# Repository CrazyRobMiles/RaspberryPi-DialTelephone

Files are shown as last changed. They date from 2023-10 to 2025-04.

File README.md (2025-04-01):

# Raspberry Pi 
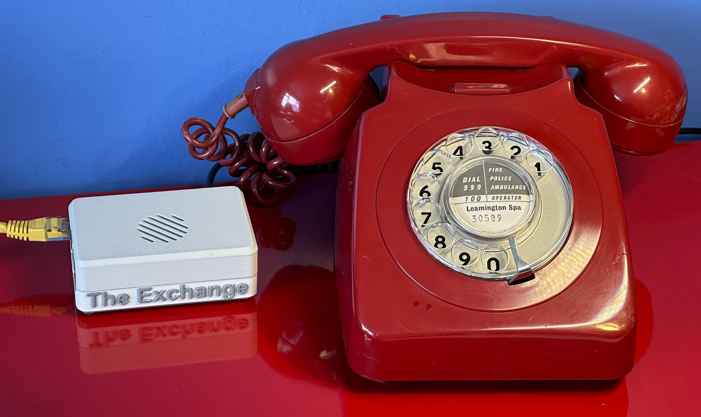
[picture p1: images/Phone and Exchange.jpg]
Red Phone


Make an old-style dial telephone into something a bit more interesting. Now with added Exchange.

## Videos

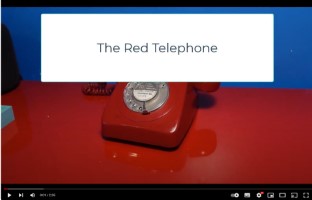
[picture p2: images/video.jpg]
YouTube Screenshot (https://youtu.be/aNzIdzsJkjI)


To find out more about the phone click on the image above to see a short video.

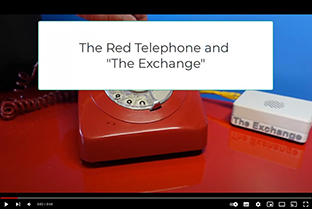
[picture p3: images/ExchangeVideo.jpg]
YouTube Screenshot (https://youtu.be/p6Ti9BQiqs0)


To see The Exchange in action click on the image above to see an  even shorter video.

## Building the device
The parts you'll need are as follows:

* An old-style telephone with a dial. The author used a 746 model he picked up in a second-hand shop. 

* I think the phone should be red, like the original “batphone” but the software will work with other colours.
* A Raspberry Pi Zero 2. Any colour you like.
* Two power switches for the bell. The author used a design which had dual D4184 MOSFETs. This can be driven directly by the GPIO signals from the Raspberry Pi.
* Two 1N4007 1A 1000V Silicon Rectifier Diodes. These are wired across the outputs from the D4184 switches so that when the bell coils are switched off the voltage induced by collapse of the magnetic in coil doesn't destroy the switch. You can see them on the circuit diagram below. Make sure you wire them the correct way round, with the band towards the positive line. 
* A power supply to convert 12 volts to 35 volts for the bell.
* A power supply to convert 12 volts to 5 volts for the Raspberry Pi.
* A 12-volt power supply for the above. 
* A Raspberry Pi GPIO breakout board to mount all the components. 
* A USB audio adapter and micro-USB “on the go” cable to connect it.

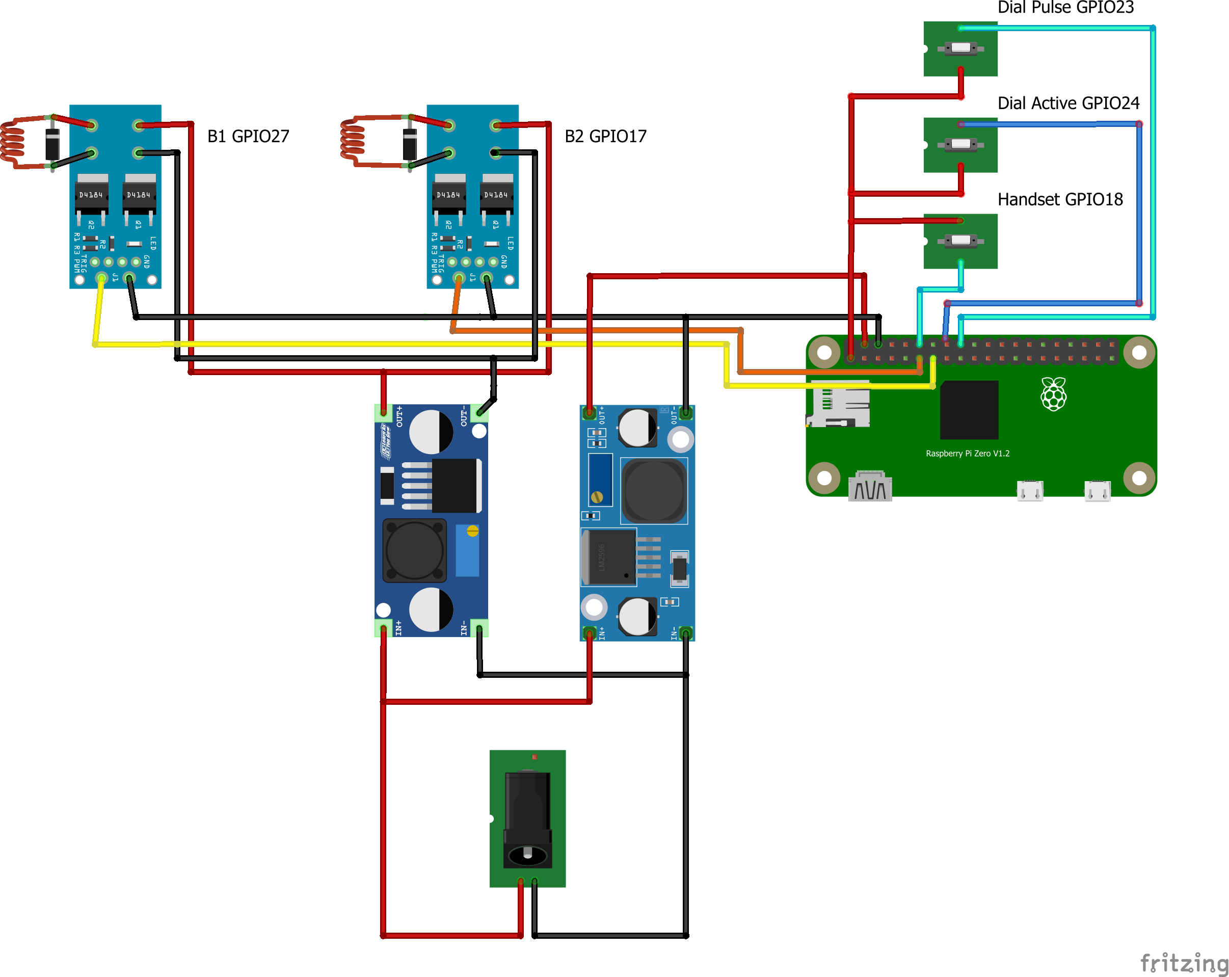
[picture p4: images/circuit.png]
Circuit diagram


The Raspberry Pi GPIO pins are shown on the circuit diagram. There is also a USB sound interface plugged into the Raspberry Pi "On the Go" usb socket via a suitable adapter. 
## Packaging the components
pi holder
There is a 3D printable design for the Raspberry Pi holder in the holder folder.
built system
This is the built system.
## Setting up the Raspberry Pi
Steps to install software:
### Make an sd card for your Pi
1. Start the Raspberry Imager program on your machine and put the microSD card into the drive on your computer. 
1. Select the OS to be installed. Make sure you are not installing a desktop. You will be using your Raspberry Pi without a screen, keyboard or mouse. (I used Debian Bullseye Light)
1. Set the advanced options in the Imager program. Now make the folling settings. 
    1. Hostname (I called mine "theredphone")
    1. Enable SSH (password authentication)
    1. User: xxxx Password: xxxxxx (don't use x, put in your own words) I created a user called rob (it's used in the ssh command a few steps down)
    1. Set Wi-Fi credentials and locale
    1. Save the options so you can use them again if you need to
1. Make the image.
### Configure your Pi
1. Remove the SD card from your computer, plug it into your Raspberry Pi and turn the Pi on. Wait a few minutes until the green led on the Pi seems to settle down a bit.
1.	Now log in from your computer. You'll need a command prompt to do this. The commands given are from Microsoft PowerShell. You will be setting up a secure shell, so use the command ssh:
    ```
    ssh theredphone.local -l rob
    ```
1.	Use the name of the computer and the username that you set in the steps above. Say yes to set up the connection if it is the first time you've connected.
1.	Give your password when it is requested.
1.  Once you've logged in you should update your computer:
    ```
    sudo apt update
    ```
1.	Now set up SSL to allow your remote machine to connect to the PI.
    1. On the Pi
        1. Check for existing SSH
            ```
            ls ~/.ssh
            ```
        1. If this comes back with some files they are already there. Otherwise:
            ```
            ssh-keygen
            ```

        1.	Use the defaults
    1.	On your remote machine
        1.	Copy your keys over:
            ```
            cat ~/.ssh/id_rsa.pub | ssh rob@theredphone.local 'mkdir -p ~/.ssh && cat >> ~/.ssh/authorized_keys'
            ```

        1. I used the username and the address of the pi I’m setting up. Enter the password for the user (in my case rob)
    1. Now you can test the connection. Open another terminal window on your remote machine and connect directly to the pi with no password:
        ```
        ssh theredphone.local -l rob
        ```
    1. This should open a remote terminal session with no password required. If this works you will be able to use remote development with Visual Studio Code.
### Install git
1. Now we need to install git on your machine:
    ```
    sudo apt-get install git -y
    ```
1. Next we need to configure the username and email values for the Git installation on the machine. Use your email and username as appropriate. 
    ```
    git config --global user.name "Rob Miles"
    git config --global user.email rob@robmiles.com
    ```
### Install node 

1.	Now install nodejs and npm:
    ```
    sudo apt install nodejs
    sudo apt install npm
    ```
### Install audio output and speech
1.  Install the audio headers for the espeak:
    ```
    sudo apt-get install libasound2-dev
    ```
1.	Now install espeak:
    ```
    sudo apt-get install espeak
    ```
1.	Now set up the audio playback. This is going to make the USB sound adapter the default audio device. If you try to run the server without the audio interface plugged in the phone software will fail:
    ```
    sudo nano /usr/share/alsa/alsa.conf
    ```
    1.  Find:
        ```
        defaults.ctl.card 0
        defaults.pcm.card 0
        ```
    1.	Change to: 
        ```
        defaults.ctl.card 1
        defaults.pcm.card 1
        ```
    1. reboot the machine
        ```
        sudo reboot
        ```
### Start developing with Visual Studio Code
Will be developing the code on our PC or laptop. The version of Visual Studio Code on that device will communicate with remote connection software running on the Raspberry Pi. 
1.	Open Visual Studio Code on your PC or laptop. 
1.	Make sure to turn off things that slow us down. 
    1. Select the Extensions tab and enter the following into the extensions search window:
        ```
        @builtin typescript
        ```
    1. Two plugins should be found. Click the gear icon and select "Disable Workspace" from the menu for each. You will lose a few useful features when editing the code, but at least the Raspberry Pi won't freeze up.
1. Ensure you have Remote Development installed on your machine. If you don't, open extensions and install it. If it is installed you will have a green icon in the bottom left of your Visual Studio Window. Click this to open a remote development window.
1.  Select "Connect to Host - Remote SSH" from the menu which appears. The first time you make the connection you will be asked to enter the username and address of your machine. I used rob@redphone.local - you use the one you set. 
1. Create a new remote connection (rob@theredphone.local)
1.	Now clone the repository.
    1. Select "Clone a repository" from the start page of Visual Studio Code and open the following repository:
    ```
    https://github.com/CrazyRobMiles/RaspberryPi-DialTelephone
    ```
1. Now we need to install all the libraries in the project (we only need to do this once)
    ```
    npm install
    ```
1. Now open a terminal window and start the server:
    ```
    node redserver.js
    ```
The server should start up and you can interact with the phone. 
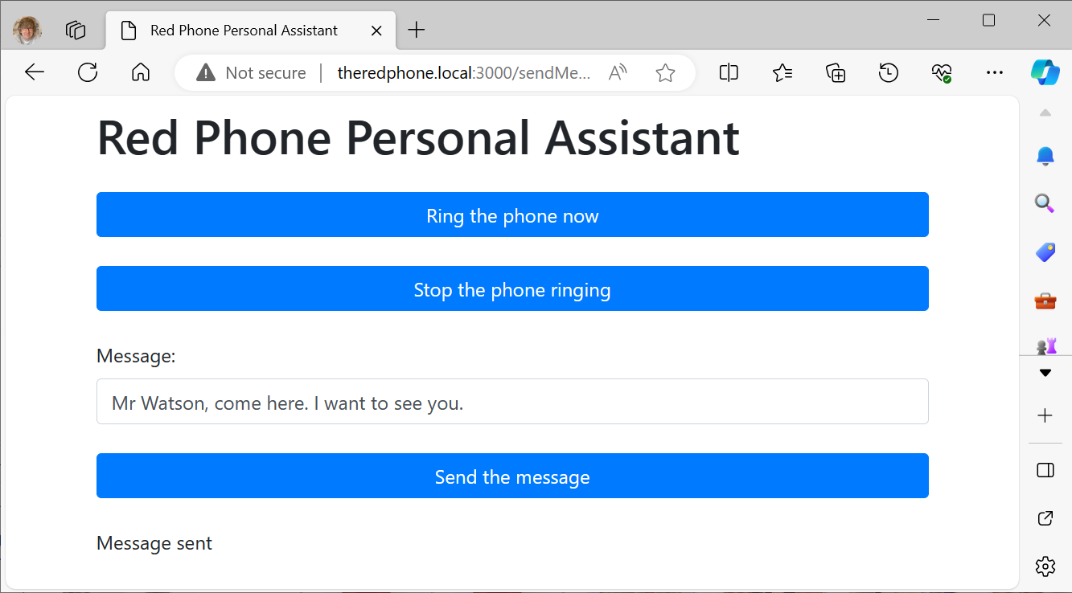
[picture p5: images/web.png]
Web Interface

If you want to make the server run automatically when the Raspberry Pi starts you can do this by editing the rc.local file. 
# Adding sound input
You can make your phone even more interesting by adding audio input. You can use this to record messages or, by using speech to text, understand voice commands. 
## Sound input circuit

You can add voice input to the phone by building a small circuit and connecting it to the carbon microphone in the telephone handset. The sound quality is not as good as a modern microphone, but it does work with speech recognition and it has the "authentic telephone" sound.

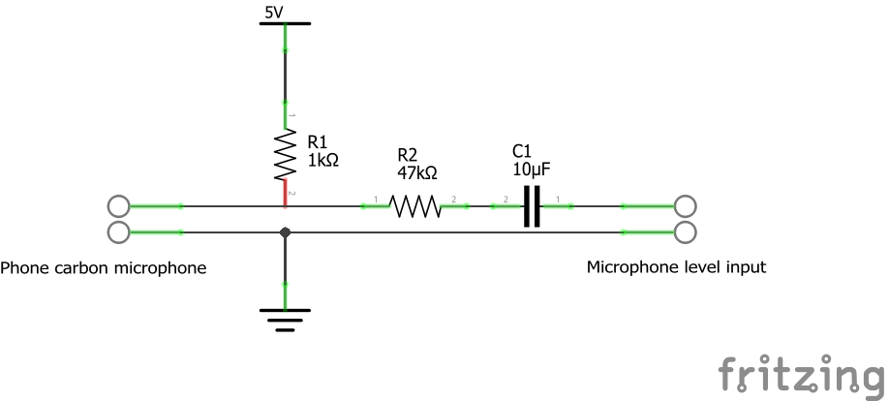
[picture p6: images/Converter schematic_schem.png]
microphone converter circuit


The circuit above alows the phone handset microphone to be connected to a standard microphone input such as the one fitted to USB audio converter you might use with a Raspberry Pi. 
## Recording audio
The application uses the mic application to record audio. It is called from within the helper function /helpers/soundInput.js.

## Speech to text software
The updated phone software uses the Spchcat program you can find [here](https://github.com/petewarden/spchcat) The program runs on a Raspberry Pi Zero but it takes a few seconds to complete a conversion. 

Follow the instructions on the repository to install the software. It is called from within the phone software by the helper function in /helpers/speechInput.js. 

# The Exchange
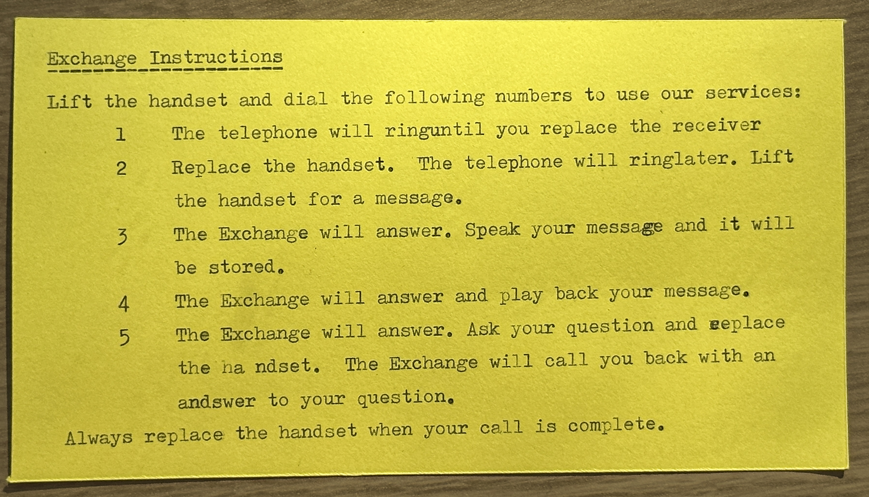
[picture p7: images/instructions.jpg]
the instructions for the telephone

"The Exchange" is a Raspberry Pi running a Large Language Mode (LLM). You will need a Raspberry Pi 5 with 8Gb of memory and an SSD. The telephone can connect to this and send it questions which will be answered by a returned telephone call. Note that in the code the exchange has the network address http://ssdpi.local. YOu can change this by editing the LLM.js code in the helpers folder.

## Installing the LLM
You can install the LLM on your Pi by following the instructions [here](https://medium.com/@wesselbraakman/run-llama-on-your-raspberry-pi-5-without-using-ollama-7ebc128ff34e). This requires the use of a Linux PC (or a Windows PC running the Windows Subsystem for Linux).
## Building and running the LLM web server
Once you have installed the LLM on your Exchange Pi and tested it with the chat program you need to build and start the web service that the Raspberry Pi phone will talk to. This is the procedure for building the server.

1.  Use Visual Studio Code to open the llma-cpp project that you installed on your Pi. 

1. Install the CMake plugin for VS Code (I installed the Microsoft one)

1. Set the development environment in Visual Studio Code (there is only one option on the PI).

1.  Install cmake on the pi.

1.  Use make from the terminal in Visual Studio Code to build the code

1.  Start the server with the command below in the Visual Studio Terminal. Note the path to the llm and also the host.
    ```
    ./server -m models/llama-7b/ggml-model-q4_0.gguf -c 2048 --host 0.0.0.0
    ```
1.  You can now browse to the page (my pi is called ssdpi)
    ```
    http://ssdpi.local:8080/ 
    ```

Have fun

Rob Miles

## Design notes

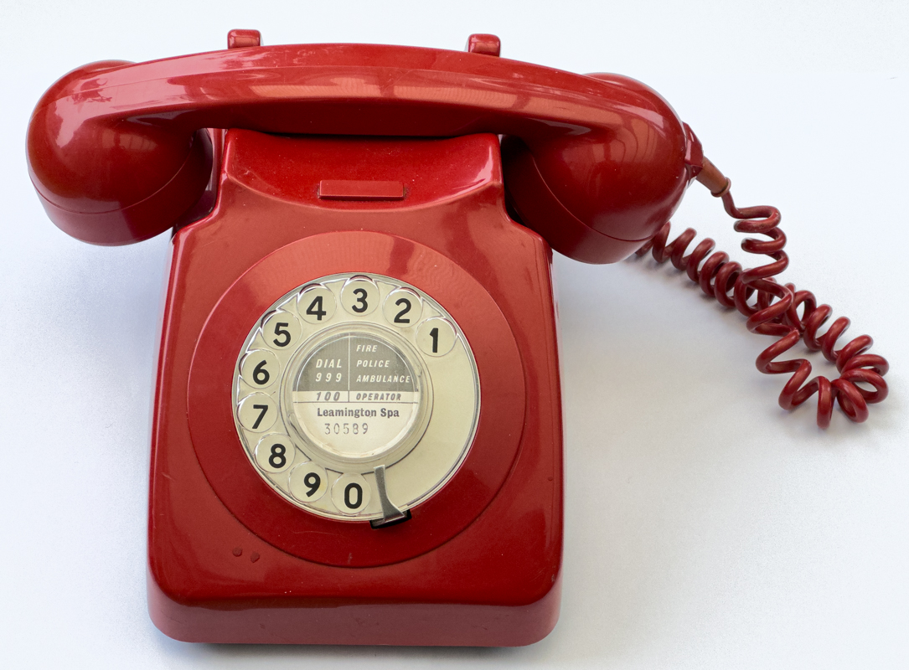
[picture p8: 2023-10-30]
images/RedPhone.jpg

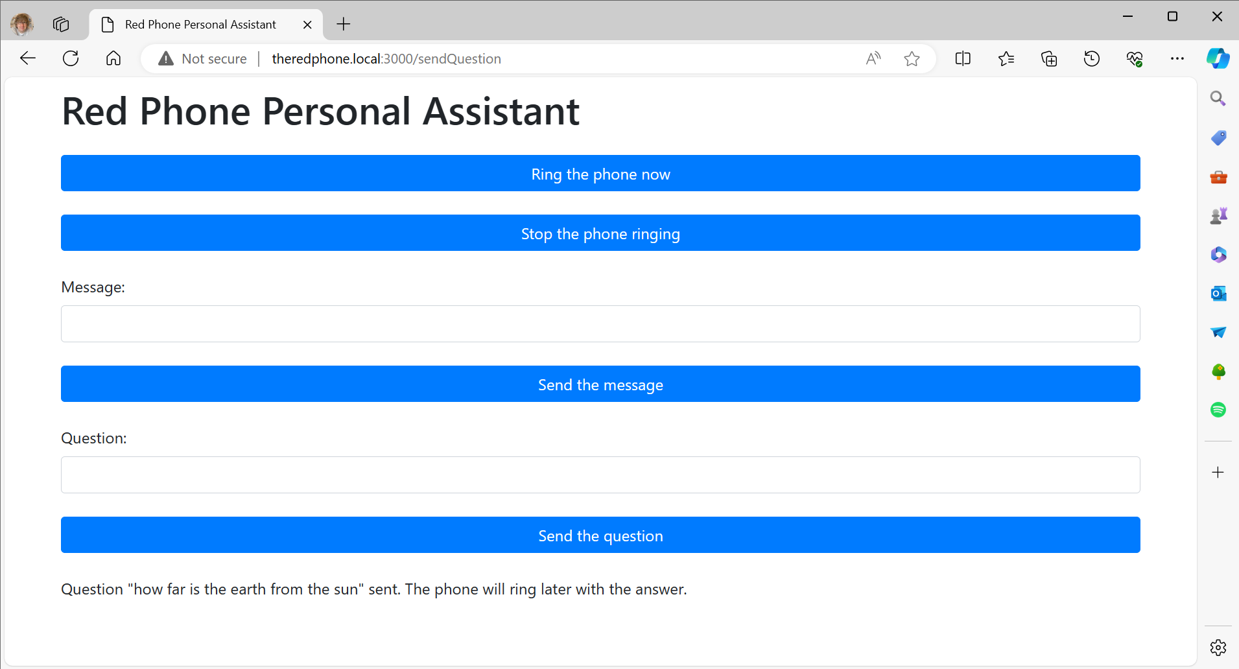
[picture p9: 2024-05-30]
images/Phone and Exchange.png

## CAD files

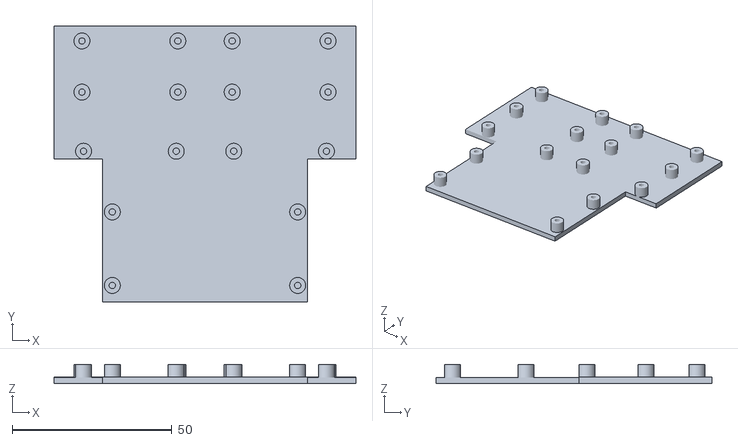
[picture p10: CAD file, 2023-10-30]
holder/PiHolder.stl
94.5 x 86.5 x 6.00

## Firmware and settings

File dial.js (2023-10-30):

const InGPIO = require('./helpers/InGPIO');

class Dial{

    dialing = false;

    pulseHandler(value){
        console.log(`Pulse handler:${value}`);
        console.log(Dial.dialing);
    }

    dialHandler(value){
        console.log(`Dial handler:${value}`);
    }

    startDialing(){
        this.dialing = true;
        this.pulseCount = 0;
        this.owner.dialStarted();
    }

    dialPulse(){
        if(this.dialing){
            this.pulseCount++;
            this.owner.dialPulse();
        }
    }

    endDialing(){
        console.log(`    Dialed a:${this.pulseCount}`);
        this.owner.numberDialed(this.pulseCount);
        this.dialing = false;
    }

    constructor(owner) {
        this.owner = owner;
        this.dialing = false;
        this.pulseCount = 0;
        let dialPulseGPIO = new InGPIO(23, (value)=> {
            if(value==1) {
                this.dialPulse();
            }
        });
        let dialingOnGPIO = new InGPIO(24,(value) => {
            if(value==1){
                this.startDialing();
            }
            else {
                this.endDialing();
            }
        });
    }
}

module.exports = Dial;

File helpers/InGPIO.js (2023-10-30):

const onoff = require('onoff'); //include onoff to interact with the GPIO

class InGPIO {

    /**
     * 
     * @param {number} GPIONumber 
     * @param {function} callback 
     */
    constructor(GPIONumber, callback) {
        this.GPIONumber = GPIONumber;
        this.callback = callback;
        this.init();
    }

    async delay(timeInMs) {
        return new Promise(async (kept, broken) => {
            setTimeout(async () => {
                return kept("tick");
            }, timeInMs);
        });
    }

    async test(){
        if(onoff.Gpio.accessible){
            console.log(`Test starting`);
            let count=0;
            this.gpio = new onoff.Gpio(this.GPIONumber, 'in', 'both', 
            {debounceTimeout:5}); 
            while(true){
                await this.delay(500);
                console.log(`Value:${this.gpio.readSync()} ${count}`);
                count++;
            }
        }
    }

    init() {
        console.log(`Initialising input GPIO ${this.GPIONumber}`);
        if(onoff.Gpio.accessible){
            // Create the input button
            this.gpio = new onoff.Gpio(this.GPIONumber, 'in', 'both', 
            {debounceTimeout:5}); 
            this.oldValue = this.gpio.readSync();
            // Watch the input for changes
            this.gpio.watch((error,value) => {
                if(error){
                    console.log(`GPIO ${this.GPIONumber} error ${error}`);
                }
                else {
                    if(this.oldValue != value){
                        // send the result to the callback
                        this.callback(value);
                    }
                    this.oldValue = value;
                }
            });
        }
        else{
            console.log("GPIO not accessible");
        }
    }

    getValue(){
        return this.oldValue;
    }
}

module.exports = InGPIO ;

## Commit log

2023-10-30 Initial Release
    [PiHolder.stl]
2025-04-01 Added diodes to the parts.
